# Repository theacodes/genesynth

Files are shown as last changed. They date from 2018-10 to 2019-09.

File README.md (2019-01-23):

# Genesynth

**Genesynth** is a music synthesizer module based around the Yamaha YM2612 FM Synthesis Chip, the same chip used in the Sega Genesis / Mega Drive.

## Why?

Because I wanted to. :)

## How?

This project is designed to use the Teensy 3.5 to control the YM2612 via USB MIDI.

More details for the hardware is available under the hardware folder, and more details on the firmware is under the firmware folder.

## License

This project is under the Apache License, Version 2.0. See LICENSE for more details.

If you use anything in this for a project, please let me know! I'd love to hear what you do with it. :)

# Building your own

This repository contains everything you'll need to build your own version of this synthesizer.

## Parts

You'll need to order all of the components in the three separate hardware modules under the `hardware` directory. You can use KiCAD to generate a BOM. These parts are readily available from Mouser and other distributors with the exception of the YM2612 chip - but this is easily obtainable on ebay.

Also note that you *must* use a Teensy 3.5. The Teensy 3.6 will *not* work as it's 3.3v logic and this design uses 5v logic.

You'll also need a 9v center-positive power supply.

## Ordering the PCBs

The gerbers for the PCBs are already created and are in the respective subdirectories under `hardware`. These are designed to fit within OSHPark's design rules, but I actually used PCBWay for my boards.

## Soldering components

You should *absolutely* use a socket for the YM2612 and the Teensy. Otherwise, this is all standard through-hole construction. Solder the smaller parts first followed by the larger parts.

## Connecting the boards.

There's three boards that make up the synth - the motherboard, a display board, and an audio board. The audio board connects to the *right* side of the motherboard, the display board to the *left*. You can connect these with wires or use pin headers and dupont connectors.

## Connect audio output.

The audo board has mono line out and stereo headphone out. You'll need to wire up the appropriate jack to the *right* side of the audio board.

## Assembling the case.

There's SVGs for creating a laser-cut case under `case`. You should be able to do this at any makerspace or using Ponoko. The case simply snaps together and the boards are mounted with standard M2 and M3 hardware.

## Preparing and programming the Teensy

Before powering on the synthesizer, **be sure to cut the USB power traces on the underside of the Teensy**. If you don't do this, **you will fry your board**. Once connected, you can build and upload the `firmware` using Teensyduino.

## Place patches on the SD card.

The synth needs patches on the SD card. Patches are in TFI format and many patch libraries are readily available. You should put patches into subdirectories of the SD card.

## All done!

You should now be able to boot the synthesizer, load patches, and play notes over MIDI. Have fun!

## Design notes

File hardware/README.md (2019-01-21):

# Genesynth Hardware

The hardware consists of three major components: the motherboard, the audio amplifier, and the display board.

## Motherboard

The motherboard contains:

* The Teensy 3.5. The 3.5 was chosen due to its 5V operating voltage for ease of compatibility with the YM2612. A 3.6 could be used if logic-level converters were added.
* A pair of LDO Voltage Regulators. These take 9V power and step it down to independent 5V supplies for digital and analog components. Since this powers the Teensy, the Teensy's USB voltage lines *must be cut*.
* The YM2612 itself. This chip should be socketed in case of a bad or damaged chip.

## Audio Amplifier

The audio amplifier is a relatively straightforward summing amplifier and buffer using the TL074 and is modeled after the Mega Amp mod for the Sega Genesis. This lets the Genesynth match the sound of the original hardware fairly closely. It's designed using through-hole components because that is what I'm most comfortable with at this time, but could easily be done using surface-mount. The audio board is powered by a dedicated analog 5V line provided by one of the motherboard's LDOs to completely eliminate noise.

## Display board

The display board holds a simple OLED display module and provides 4 tac switches for displaying and navigating the menu.

## Shared Libraries

I used the [SparkFun KiCad Libraries](https://github.com/sparkfun/SparkFun-KiCad-Libraries) for some of the footprints.

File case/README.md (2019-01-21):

# Case

This is the pattern for a laser-cut case to hold the Genesynth's various boards.

I made mine out of 1/8" acrylic and used standard M2 and M3 screws and spacers to put it all together.

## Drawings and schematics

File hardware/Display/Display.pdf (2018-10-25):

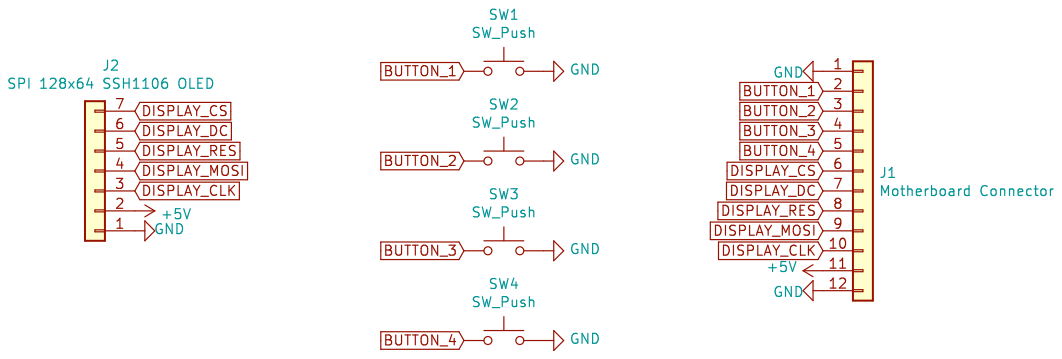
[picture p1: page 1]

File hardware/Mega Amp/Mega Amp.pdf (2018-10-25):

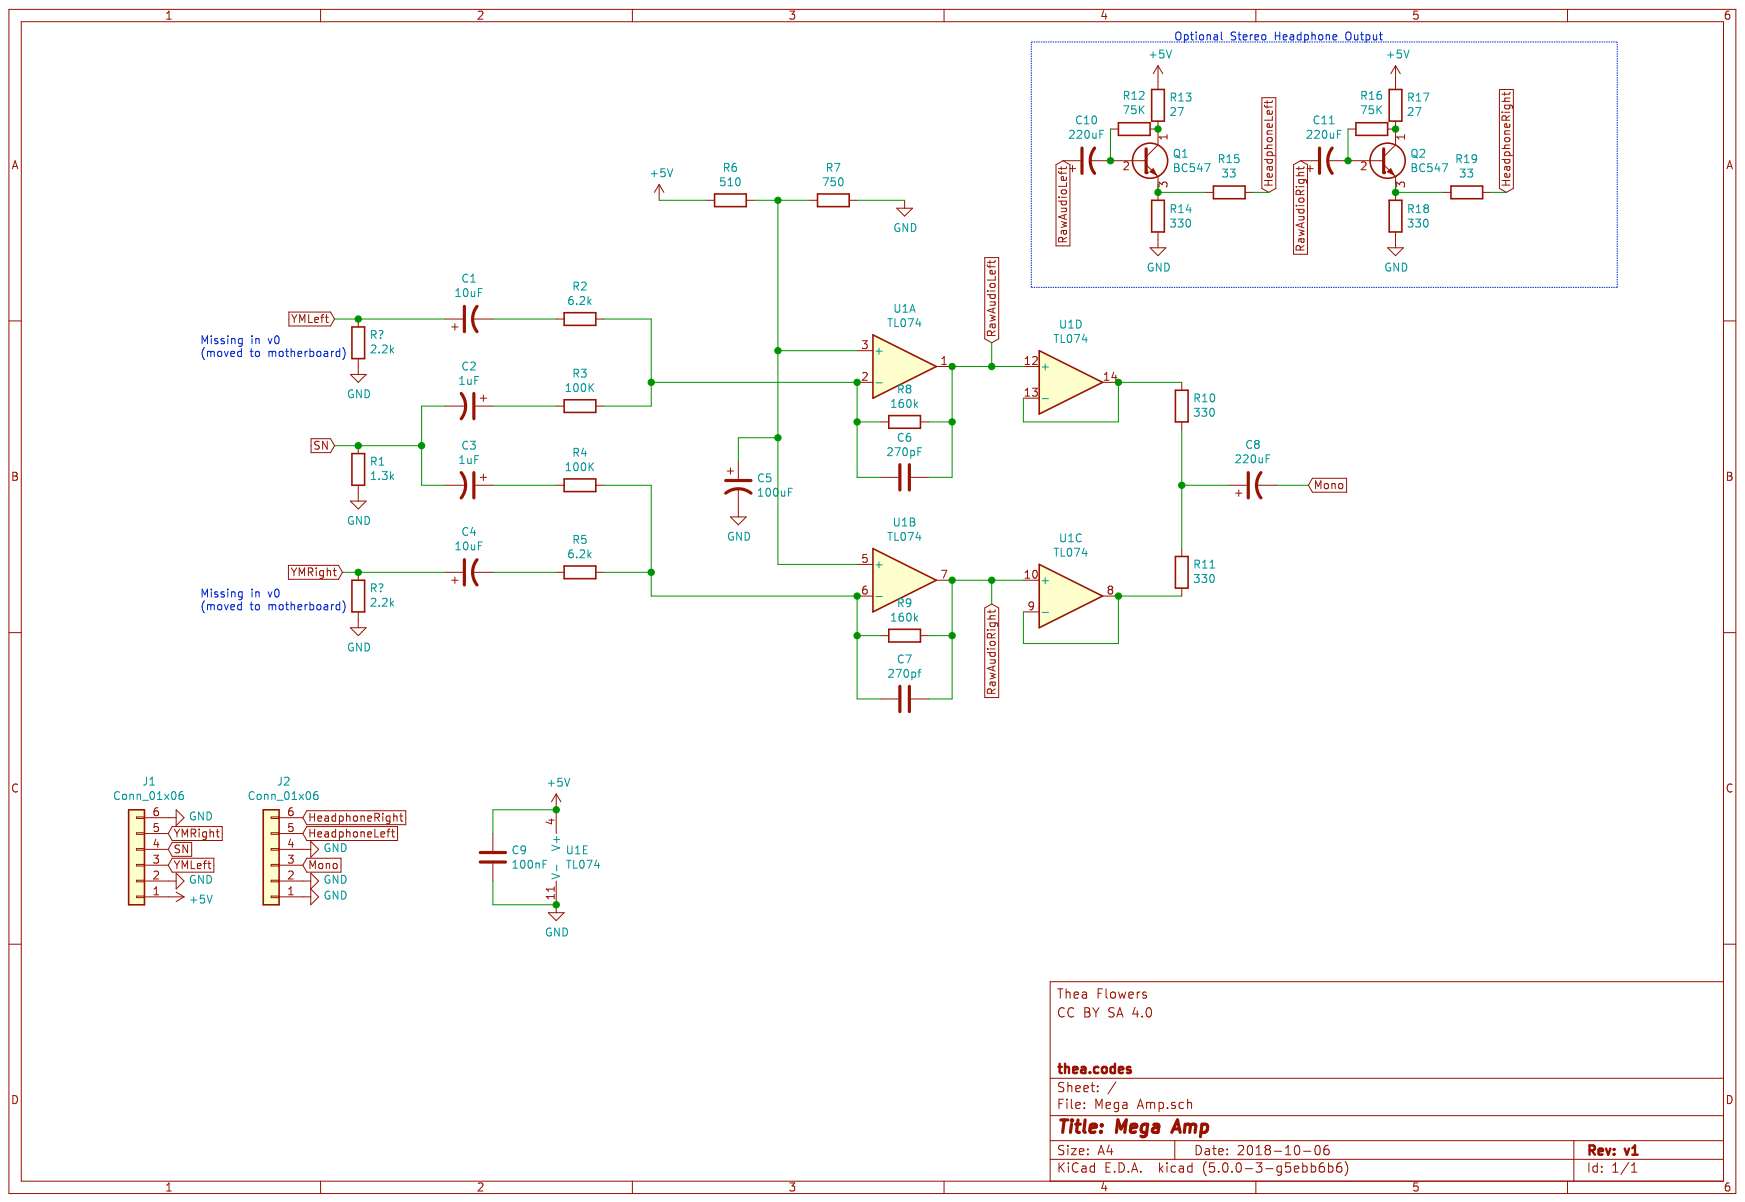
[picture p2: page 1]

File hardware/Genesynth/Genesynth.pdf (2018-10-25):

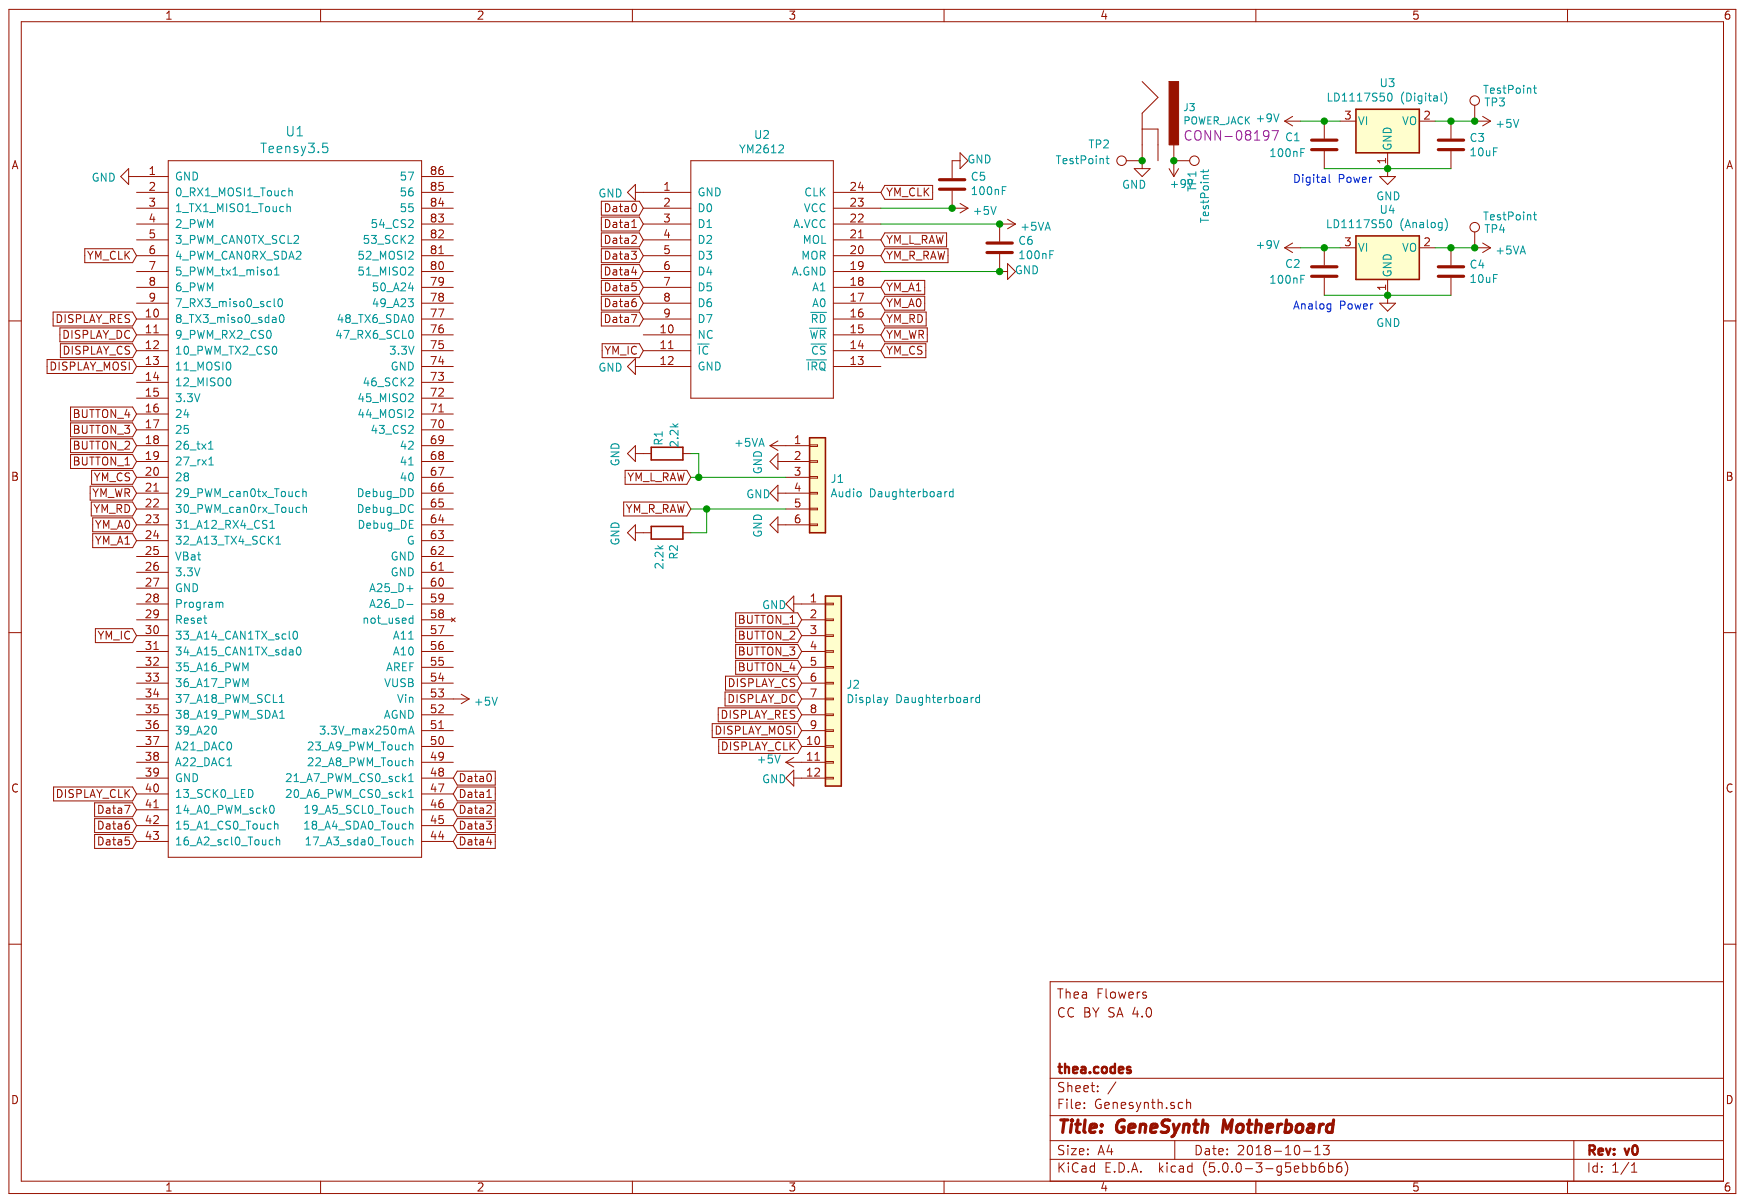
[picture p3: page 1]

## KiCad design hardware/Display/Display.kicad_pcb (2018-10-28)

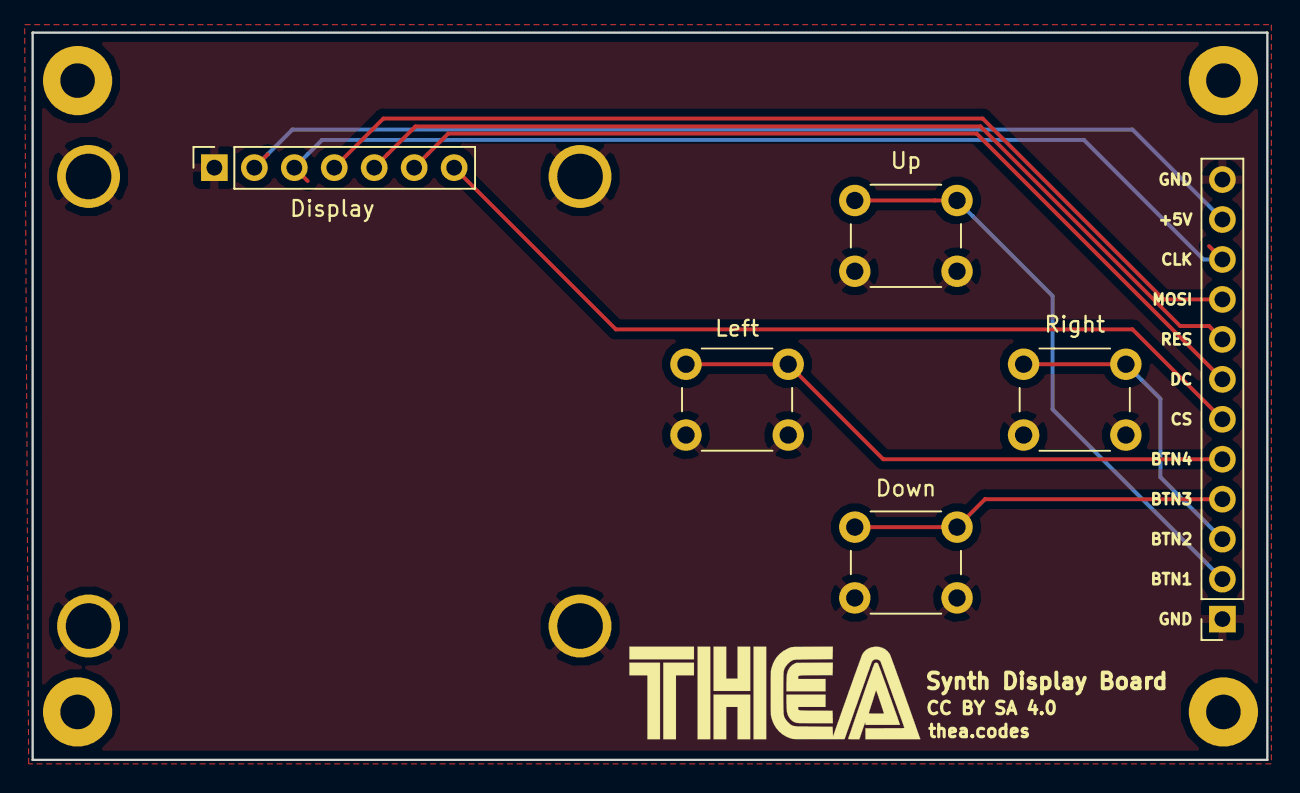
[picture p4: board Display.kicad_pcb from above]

Board: 2 copper layers, 78.5 x 46.2 mm, 6 parts (0 on the bottom side), 11 nets.

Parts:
Display: SPI 128x64 SSH1106 OLED; OLED
Down: SW_Push; SW_PUSH_6mm_H9.5mm
J1: Motherboard Connector; PinSocket_1x12_P2.54mm_Vertical
Left: SW_Push; SW_PUSH_6mm_H9.5mm
Right: SW_Push; SW_PUSH_6mm_H9.5mm
Up: SW_Push; SW_PUSH_6mm_H9.5mm

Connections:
+5V: Display.2, J1.11
BUTTON_1: J1.2, Up.1
BUTTON_2: J1.3, Right.1
BUTTON_3: Down.1, J1.4
BUTTON_4: J1.5, Left.1
DISPLAY_CLK: Display.3, J1.10
DISPLAY_CS: Display.7, J1.6
DISPLAY_DC: Display.6, J1.7
DISPLAY_MOSI: Display.4, J1.9
DISPLAY_RES: Display.5, J1.8
GND: Display.1, Down.2, J1.1, J1.12, Left.2, Right.2, Up.2

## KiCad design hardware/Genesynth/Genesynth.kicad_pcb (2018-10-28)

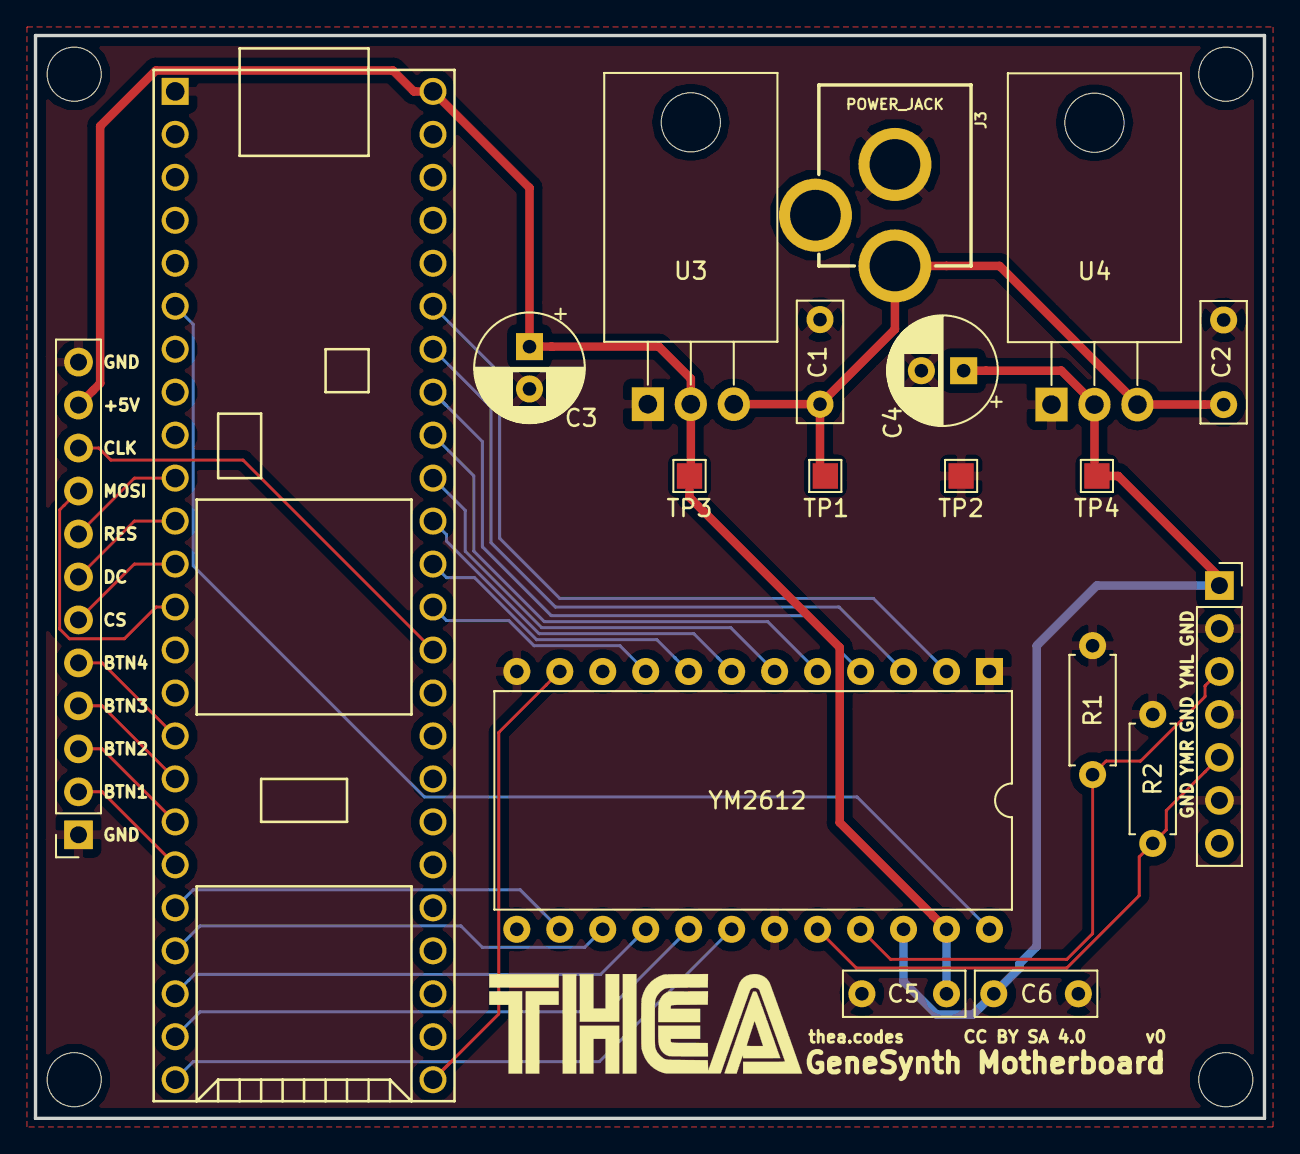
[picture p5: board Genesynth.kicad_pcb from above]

Board: 2 copper layers, 72.6 x 64.0 mm, 19 parts (0 on the bottom side), 30 nets.

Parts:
C1, C2, C5, C6: 100nF; C_Disc_D7.0mm_W2.5mm_P5.00mm
C3, C4: 10uF; CP_Radial_D6.3mm_P2.50mm
J1: Audio Daughterboard; PinSocket_1x07_P2.54mm_Vertical
J2: Display Daughterboard; PinSocket_1x12_P2.54mm_Vertical
J3: POWER_JACK; POWER_JACK_PTH
R1, R2: 2.2k; R_Axial_DIN0207_L6.3mm_D2.5mm_P7.62mm_Horizontal
TP1, TP2, TP3, TP4: TestPoint; TestPoint_Pad_1.5x1.5mm
U1: Teensy3.5; TeensyReduced
U2: YM2612; DIP-24_W15.24mm
U3: LD1117S50 (Digital); TO-220-3_Horizontal_TabDown
U4: LD1117S50 (Analog); TO-220-3_Horizontal_TabDown

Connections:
+5V: C3.1, C5.1, J2.11, TP3.1, U1.53, U2.23, U3.2
+5VA: C4.1, C6.1, J1.1, TP4.1, U2.22, U4.2
+9V: C1.1, C2.1, J3.PWR, TP1.1, U3.3, U4.3
BUTTON_1: J2.2, U1.19
BUTTON_2: J2.3, U1.18
BUTTON_3: J2.4, U1.17
BUTTON_4: J2.5, U1.16
DISPLAY_CLK: J2.10, U1.40
DISPLAY_CS: J2.6, U1.12
DISPLAY_DC: J2.7, U1.11
DISPLAY_MOSI: J2.9, U1.13
DISPLAY_RES: J2.8, U1.10
Data0: U1.48, U2.2
Data1: U1.47, U2.3
Data2: U1.46, U2.4
Data3: U1.45, U2.5
Data4: U1.44, U2.6
Data5: U1.43, U2.7
Data6: U1.42, U2.8
Data7: U1.41, U2.9
GND: C1.2, C2.2, C3.2, C4.2, C5.2, C6.2, J1.2, J1.4, J1.6, J2.1, J2.12, J3.GND, R1.2, R2.2, TP2.1, U1.1, U2.1, U2.12, U2.19, U3.1, U4.1
YM_A0: U1.23, U2.17
YM_A1: U1.24, U2.18
YM_CLK: U1.6, U2.24
YM_CS: U1.20, U2.14
YM_IC: U1.30, U2.11
YM_L_RAW: J1.3, R1.1, U2.21
YM_RD: U1.22, U2.16
YM_R_RAW: J1.5, R2.1, U2.20
YM_WR: U1.21, U2.15

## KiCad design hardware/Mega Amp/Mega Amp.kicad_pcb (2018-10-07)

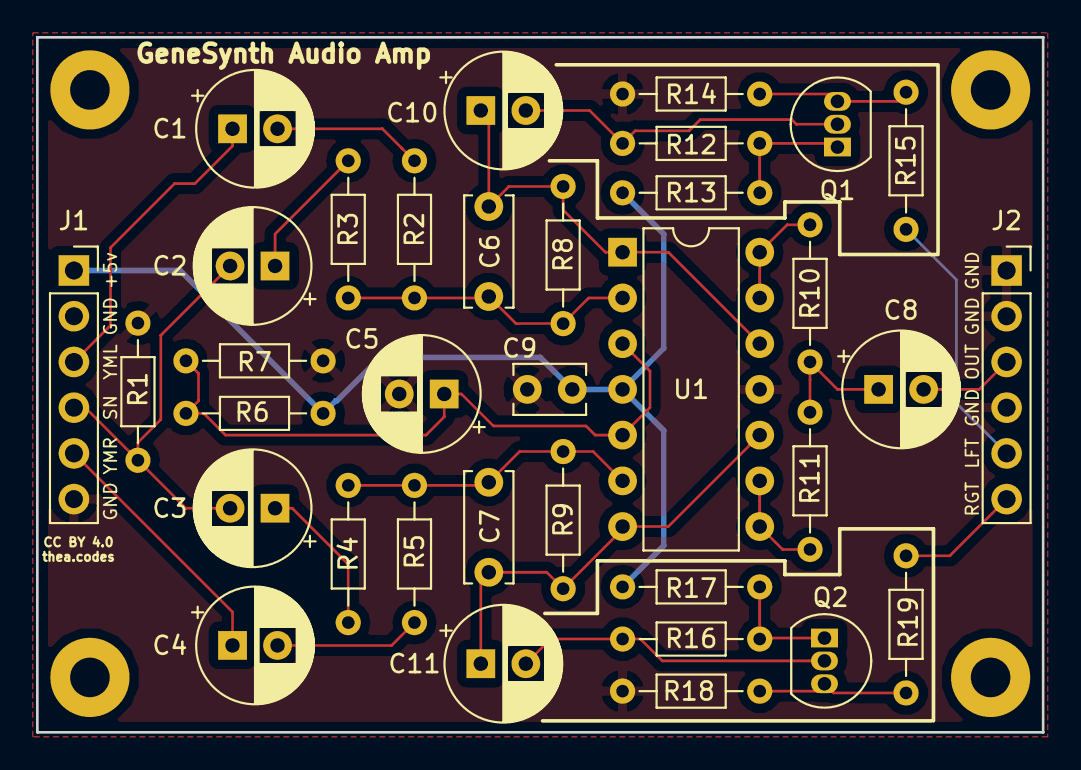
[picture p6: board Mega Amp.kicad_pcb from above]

Board: 2 copper layers, 55.9 x 38.6 mm, 35 parts (0 on the bottom side), 26 nets.

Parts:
C1, C4: 10uF; CP_Radial_D6.3mm_P2.50mm
C2, C3: 1uF; CP_Radial_D6.3mm_P2.50mm
C5: 100uF; CP_Radial_D6.3mm_P2.50mm
C6: 270pF; C_Disc_D6.0mm_W2.5mm_P5.00mm
C7: 270pf; C_Disc_D6.0mm_W2.5mm_P5.00mm
C8, C10, C11: 220uF; CP_Radial_D6.3mm_P2.50mm
C9: 100nF; C_Disc_D3.8mm_W2.6mm_P2.50mm
J1, J2: Conn_01x06; PinSocket_1x06_P2.54mm_Vertical
Q1, Q2: BC547; TO-92_Inline
R1: R; R_Axial_DIN0204_L3.6mm_D1.6mm_P7.62mm_Horizontal
R2, R5: 51K; R_Axial_DIN0204_L3.6mm_D1.6mm_P7.62mm_Horizontal
R3, R4: 100K; R_Axial_DIN0204_L3.6mm_D1.6mm_P7.62mm_Horizontal
R6: 510; R_Axial_DIN0204_L3.6mm_D1.6mm_P7.62mm_Horizontal
R7: 750; R_Axial_DIN0204_L3.6mm_D1.6mm_P7.62mm_Horizontal
R8, R9: 160; R_Axial_DIN0204_L3.6mm_D1.6mm_P7.62mm_Horizontal
R10, R11, R14, R18: 330; R_Axial_DIN0204_L3.6mm_D1.6mm_P7.62mm_Horizontal
R12, R16: 75K; R_Axial_DIN0204_L3.6mm_D1.6mm_P7.62mm_Horizontal
R13, R17: 27; R_Axial_DIN0204_L3.6mm_D1.6mm_P7.62mm_Horizontal
R15, R19: 33; R_Axial_DIN0204_L3.6mm_D1.6mm_P7.62mm_Horizontal
U1: TL074; DIP-14_W7.62mm

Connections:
+5V: C9.1, J1.1, R6.2, R13.2, R17.2, U1.4
GND: C5.2, C9.2, J1.2, J1.6, J2.1, J2.2, J2.4, R1.1, R7.1, R14.2, R18.2, U1.11
HeadphoneLeft: J2.5, R15.2
HeadphoneRight: J2.6, R19.2
Mono: C8.2, J2.3
unnamed: C1.2, R2.2
unnamed: C2.1, R3.2
unnamed: C3.1, R4.2
unnamed: C4.2, R5.2
unnamed: C5.1, R6.1, R7.2, U1.3, U1.5
unnamed: C6.2, R2.1, R3.1, R8.2, U1.2
unnamed: C7.2, R4.1, R5.1, R9.2, U1.6
unnamed: C8.1, R10.1, R11.2
unnamed: C10.2, Q1.2, R12.1
unnamed: C11.2, Q2.2, R16.1
unnamed: Q1.1, R12.2, R13.1
unnamed: Q1.3, R14.1, R15.1
unnamed: Q2.1, R16.2, R17.1
unnamed: Q2.3, R18.1, R19.1
unnamed: R10.2, U1.13, U1.14
unnamed: R11.1, U1.8, U1.9
RawAudioLeft: C6.1, C10.1, R8.1, U1.1, U1.12
RawAudioRight: C7.1, C11.1, R9.1, U1.7, U1.10
SN: C2.2, C3.2, J1.4, R1.2
YMLeft: C1.1, J1.3
YMRight: C4.1, J1.5

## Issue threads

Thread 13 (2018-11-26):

figure out what to do with the modwheel

theacodes, 2018-11-26:

theacodes, 2019-01-15:
I should implement a modulation "matrix" - with the modulation source being fixed to just the mod wheel but with many modulation destinations.

Closed 2019-09-05.

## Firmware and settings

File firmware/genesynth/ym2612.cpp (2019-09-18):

#include <Arduino.h>

#include "hardware_constants.h"
#include "nanodelay.h"
#include "ym2612.h"

namespace thea {
namespace ym2612 {

/* Global state */

struct WriteCommand {
  uint8_t address = 0;
  uint8_t data = 0;
  uint8_t port = 0;
};

// 200 is a good size here, as it takes about 150 commands to write a full
// patch.
WriteCommand write_buffer[200];
const size_t write_buffer_size = sizeof(write_buffer) / sizeof(WriteCommand);
size_t write_buffer_len = 0;
size_t write_buffer_start = 0;
size_t write_buffer_end = 0;

LatencyInfo latency;

/* Low-level functions */

static void initialize_clock() {
  /* Uses PWM to generate clock for the YM2612 */
  pinMode(YM_CLOCK, OUTPUT);
  analogWriteFrequency(YM_CLOCK, YM_CLOCK_FREQ);
  analogWrite(YM_CLOCK, 128);
  delay(50); // wait a moment for the clock.
}

static void reset() {
  /* Reset the YM's state. */
  digitalWriteFast(YM_IC, HIGH);
  delayMicroseconds(YM_RESET_WAIT);
  digitalWriteFast(YM_IC, LOW);
  delayMicroseconds(YM_RESET_WAIT);
  digitalWriteFast(YM_IC, HIGH);
  delayMicroseconds(YM_RESET_WAIT);
}

inline static void input_enable() {
  for (int i = 0; i < 8; i++) {
    pinMode(YM_DATA - i, INPUT);
  }
}

inline static void output_enable() {
  for (int i = 0; i < 8; i++) {
    pinMode(YM_DATA - i, OUTPUT);
  }
}

inline static uint8_t read_data_lines() {
  uint8_t out = 0;
  for (int i = 0; i < 8; i++) {
    out |= digitalReadFast(YM_DATA - i) << i;
  }
  return out;
}

inline static void set_data_lines(byte b) {
  /* Sets the data lines to the YM to the given byte. */
  for (int i = 0; i < 8; i++) {
    digitalWriteFast(YM_DATA - i, ((b >> i) & 1));
  }
}

inline static void wait_ready() {
  // Always wait a few nano seconds before toggling pin directions.
  delay10ns(YM_WRITE_WAIT);

  // Switch data bus to input YM -> uC.
  input_enable();

  // Switch A0 to inactive to read the data byte, pull CS and RD low again.
  digitalWriteFast(YM_WR, HIGH);
  digitalWriteFast(YM_A1, LOW);
  digitalWriteFast(YM_A0, LOW);
  digitalWriteFast(YM_RD, LOW);
  delay10ns(YM_WRITE_WAIT);
  digitalWriteFast(YM_CS, LOW);
  delay10ns(YM_WRITE_WAIT);

  // Wait until the bus' 7th bit is 0.
  int count = 0;
  uint8_t state = 0;
  while (count < YM_MAX_WAIT_CYCLES) {
    __asm__ volatile("nop");
    count++;
    // Wait at *least* 20 cycles for the pins to read accurately.
    if (count < 20)
      continue;
    state = read_data_lines();
    if ((state & (1 << 7)) == 0)
      break;
  }

  // Disable the chip and read pins.
  digitalWriteFast(YM_RD, HIGH);
  digitalWriteFast(YM_CS, HIGH);
  delay10ns(YM_WRITE_WAIT);

  // Switch data bus back to ouput. uC -> YM.
  output_enable();

  // Debug
  if (count == YM_MAX_WAIT_CYCLES) {
    Serial.printf("Warning, waited too many cycles for ready, last state: %x, %x, %i.\n", state, (1 << 7),
                  state & (1 << 7));
    latency.hit_max_wait_cycles = true;
  }
}

static void write_out_reg(uint8_t address, uint8_t data, uint8_t port) {
  // Serial.printf("Writing %02x to %02x on %i\n", data, address, port);
  auto start = micros();

  // Wait for any previous writes to finish before writing.
  wait_ready();

  // Write the register address first.
  digitalWriteFast(YM_A1, port);
  digitalWriteFast(YM_A0, LOW);
  set_data_lines(address);

  // technically we should give *some* time between setting the bytes and
  // pulling the pins, but it seems to work fine without that.
  digitalWriteFast(YM_CS, LOW);
  digitalWriteFast(YM_WR, LOW);

  // We must wait for the chip to finish reading our address before loading in the
  // next byte.
  // We shouldn't raise the WR and CS until at least YM_WRITE_WAIT have passed.
  delay10ns(YM_WRITE_WAIT);
  digitalWriteFast(YM_WR, HIGH);
  digitalWriteFast(YM_CS, HIGH);

  // Same as above, but with A0 high to write the register data.
  digitalWriteFast(YM_A0, HIGH);
  set_data_lines(data);
  delay10ns(YM_WRITE_WAIT);
  digitalWriteFast(YM_CS, LOW);
  digitalWriteFast(YM_WR, LOW);
  delay10ns(YM_WRITE_WAIT);

  // Disable the chip and write pins.
  digitalWriteFast(YM_WR, HIGH);
  digitalWriteFast(YM_CS, HIGH);
  delay10ns(YM_WRITE_WAIT);

  // Update latency calculations
  latency.last = micros() - start;
  if (latency.max < latency.last)
    latency.max = latency.last;
  latency.average = (latency.average_alpha * latency.last) + (1.f - latency.average_alpha) * latency.average;
  latency.bytes_written++;
}

/* Top-level functions */

void setup() {
  /* Setup the YM's pins. */
  for (int i = 0; i < 8; i++) {
    pinMode(YM_DATA - i, OUTPUT);
    digitalWriteFast(YM_DATA - i, LOW);
  }
  pinMode(YM_IC, OUTPUT);
  pinMode(YM_A1, OUTPUT);
  pinMode(YM_A0, OUTPUT);
  pinMode(YM_WR, OUTPUT);
  pinMode(YM_CS, OUTPUT);
  pinMode(YM_RD, OUTPUT);
  digitalWriteFast(YM_IC, HIGH);
  digitalWriteFast(YM_A1, LOW);
  digitalWriteFast(YM_A0, LOW);
  digitalWriteFast(YM_WR, HIGH);
  digitalWriteFast(YM_CS, HIGH);
  digitalWriteFast(YM_RD, HIGH);

  initialize_clock();
  reset();
}

void loop() {
  if (!write_buffer_len)
    return;
  // Serial.printf("There are %u commands to send.\n", write_buffer_len);
  while (write_buffer_len) {
    // Serial.printf("start: %u, end: %u, len: %u\n", write_buffer_start, write_buffer_end, write_buffer_len);
    auto command = write_buffer[write_buffer_start];
    write_out_reg(command.address, command.data, command.port);
    write_buffer_start = (write_buffer_start + 1) % write_buffer_size;
    write_buffer_len--;
  }
}

const LatencyInfo &get_latency() { return latency; }

void set_reg(uint8_t address, uint8_t data, uint8_t port) {
  /* Queues a write command into the command buffer.*/

  // Is this one of the parameter modifications? If so, de-duplicate the
  // command to prevent overwhelming the ym2612.
  if (address >= 0x30 && address <= 0x90) {
    // step through the whole buffer and see if there's already a command
    // queued. If so, modify it instead of inserting this.
    for (auto i = 0; i < write_buffer_len; i++) {
      auto &command = write_buffer[(write_buffer_start + i) % write_buffer_size];
      if (command.address == address && command.port == port) {
        // Serial.printf("Deduplicated a write to %02x:%u old: %02x new: %02x\n", address, port, command.data, data);
        command.data = data;
        return;
      }
    }
  }

  // Otherwise, insert the new command.
  write_buffer[write_buffer_end].address = address;
  write_buffer[write_buffer_end].data = data;
  write_buffer[write_buffer_end].port = port;
  write_buffer_end = (write_buffer_end + 1) % write_buffer_size;
  write_buffer_len++;
}

void set_reg(uint8_t address, uint8_t data) { return set_reg(address, data, 0); }

void set_channel_freq(int channel, float freq) {
  // From YM2612 Datasheet:
  // Freq Number = (144 * note * 2^20 / Clock) / 2^(block-1)
  // (change to 2^20, because it seemed to be setting the wrong octaive).
  // Figure out the base frequency number first, then start iterating through
  // blocks until it's within range 0 < freq_int < 2000
  float base_freq = 144.f * freq * pow(2.f, 19) / 7500000.f;
  uint32_t freq_int = 2001;

  int block = 1;
  while (freq_int > 2000) {
    freq_int = base_freq / pow(2.f, block - 1);
    block++;
  }

  int port = channel < 3 ? 0 : 1;
  uint8_t channel_offset = (channel % 3);
  set_reg(0xA4 + channel_offset, (block << 3) | (freq_int >> 8), port);
  set_reg(0xA0 + channel_offset, freq_int & 0xFF, port);
}

void play_note(int channel) {
  int port = channel < 3 ? 0 : 1;
  uint8_t channel_offset = (channel % 3);
  uint8_t key_offset = channel_offset | (port << 2);
  set_reg(0x28, 0xF0 | key_offset);
}

void stop_note(int channel) {
  int port = channel < 3 ? 0 : 1;
  uint8_t channel_offset = (channel % 3);
  uint8_t key_offset = channel_offset | (port << 2);
  set_reg(0x28, key_offset);
}

void set_lfo(bool enable, uint8_t freq) {
  if (freq > 7)
    freq = 7; // 3 bits (0-7)
  uint8_t lfo_reg = (enable << 3) | (freq);
  set_reg(0x22, lfo_reg);
}

/* Channel/OperatorPatch implementations */

static void write_operator_values(int port, int channel, int operator_num, OperatorPatch &oper,
                                  ChannelPatch::WriteOption option) {
  // wrap the write option around if its an operator specific option in *this* operator's range.
  if (option >= 10 * operator_num && option <= 10 * (operator_num + 1)) {
    option = ChannelPatch::WriteOption(option % 10);
  }
  // If this wasn't an operator-specific option and also not a option to write
  // All params, then there's nothing to do here.
  else if (option != ChannelPatch::WriteOption::ALL) {
    return;
  }

  uint8_t operator_offset = 4 * operator_num;

  uint8_t dt1_mul_byte = (oper.DT1 << 4) | (oper.MUL & 0xF);
  uint8_t tl_byte = oper.TL & 0x7F;
  uint8_t rs_ar_byte = (oper.RS << 6) | (oper.AR & 0x1F);
  uint8_t am_d1r_byte = (oper.AM << 7) | (oper.D1R & 0x1F);
  uint8_t d2r_byte = oper.D2R & 0x1F;
  uint8_t d1l_rr_byte = (oper.D1L << 4) | (oper.RR & 0xF);

  if (option == ChannelPatch::WriteOption::ALL or option == ChannelPatch::WriteOption::OP0_DT1 or
      option == ChannelPatch::WriteOption::OP0_MUL) {
    set_reg(0x30 + operator_offset + channel, dt1_mul_byte, port);
  }

  if (option == ChannelPatch::WriteOption::ALL or option == ChannelPatch::WriteOption::OP0_TL) {
    set_reg(0x40 + operator_offset + channel, tl_byte, port);
  }

  if (option == ChannelPatch::WriteOption::ALL or option == ChannelPatch::WriteOption::OP0_RS or
      option == ChannelPatch::WriteOption::OP0_AR) {
    set_reg(0x50 + operator_offset + channel, rs_ar_byte, port);
  }

  if (option == ChannelPatch::WriteOption::ALL or option == ChannelPatch::WriteOption::OP0_AM or
      option == ChannelPatch::WriteOption::OP0_D1R) {
    set_reg(0x60 + operator_offset + channel, am_d1r_byte, port);
  }

  if (option == ChannelPatch::WriteOption::ALL or option == ChannelPatch::WriteOption::OP0_D2R) {
    set_reg(0x70 + operator_offset + channel, d2r_byte, port);
  }

  if (option == ChannelPatch::WriteOption::ALL or option == ChannelPatch::WriteOption::OP0_D1L or
      option == ChannelPatch::WriteOption::OP0_RR) {
    set_reg(0x80 + operator_offset + channel, d1l_rr_byte, port);
  }
};

void ChannelPatch::write_to_channel(uint8_t channel, ChannelPatch::WriteOption option) {
  int port = channel < 3 ? 0 : 1;
  channel = channel % 3;

  for (int i = 0; i < 4; i++) {
    write_operator_values(port, channel, i, operators[i], option);
  }

  // Setup channel
  uint8_t feedback_algorithm_byte = (feedback << 3) | (algorithm & 0x7);

  if (option == WriteOption::ALL or option == WriteOption::FEEDBACK or option == WriteOption::ALGORITHM) {
    set_reg(0xB0 + channel, feedback_algorithm_byte, port);
  }

  if (option == WriteOption::ALL || option == WriteOption::LFO_AMS || option == WriteOption::LFO_FMS) {
    // Enable output on both speakers (for now) with 0xC0
    uint8_t lr_ams_fms_byte = 0xC0 | (lfo_ams << 5) | (lfo_fms);
    set_reg(0xB4 + channel, lr_ams_fms_byte, port);
  }
};

void ChannelPatch::set_parameter(ChannelPatch::WriteOption option, uint8_t value, bool normalized) {
  if (normalized)
    value = normalized_to_ym2612(value, option);

  /* Global parameters */
  switch (option) {
  case WriteOption::ALGORITHM:
    algorithm = value;
    return;
  case WriteOption::FEEDBACK:
    feedback = value;
    return;
  case WriteOption::LFO_FMS:
    lfo_fms = value;
    return;
  case WriteOption::LFO_AMS:
    lfo_ams = value;
    return;
  default:
    break;
  }

  /* Operator parameters */
  if (option > thea::ym2612::ChannelPatch::WriteOption::OP3_AM) {
    /* Unknown option */
    return;
  }

  auto normalized_option = thea::ym2612::ChannelPatch::WriteOption(option % 10);
  auto operator_no = option / 10;

  switch (normalized_option) {
  case WriteOption::OP0_DT1:
    operators[operator_no].DT1 = value;
    break;
  case WriteOption::OP0_MUL:
    operators[operator_no].MUL = value;
    break;
  case WriteOption::OP0_TL:
    operators[operator_no].TL = value;
    break;
  case WriteOption::OP0_AR:
    operators[operator_no].AR = value;
    break;
  case WriteOption::OP0_D1R:
    operators[operator_no].D1R = value;
    break;
  case WriteOption::OP0_D2R:
    operators[operator_no].D2R = value;
    break;
  case WriteOption::OP0_D1L:
    operators[operator_no].D1L = value;
    break;
  case WriteOption::OP0_RR:
    operators[operator_no].RR = value;
    break;
  case WriteOption::OP0_RS:
    operators[operator_no].RS = value;
    break;
  case WriteOption::OP0_AM:
    operators[operator_no].AM = value;
    break;
  default:
    break;
  }
}

/* Normalization / denormalization routines */

uint8_t ym2612_to_normalized(uint8_t value, ChannelPatch::WriteOption option) {
  // TODO
  return 0;
}

uint8_t normalized_to_ym2612(uint8_t value, ChannelPatch::WriteOption option) {
  // Is this a global parameter?
  switch (option) {
  case ChannelPatch::WriteOption::ALGORITHM:
    return map(value, 0, 127, 0, 7);
  case ChannelPatch::WriteOption::FEEDBACK:
    return map(value, 0, 127, 0, 7);
  case ChannelPatch::WriteOption::LFO_FMS:
    return map(value, 0, 127, 0, 7);
  case ChannelPatch::WriteOption::LFO_AMS:
    return map(value, 0, 127, 0, 3);
  default:
    break;
  }

  // This is an operator value.
  auto normalized_option = thea::ym2612::ChannelPatch::WriteOption(option % 10);
  uint8_t operator_no = option / 10;

  // All operator parameters are actually inverted - the lower values are
  // associated with what humans would think are "higher" knob values. That is
  // to say, if the parameter were "volume", 0 would be the loudest and 127
  // would be the softest. No frickin' clue why Yamaha did this.
  value = 127 - value;

  switch (normalized_option) {
  case thea::ym2612::ChannelPatch::WriteOption::OP0_DT1:
    return map(value, 0, 127, 0, 7);
  case thea::ym2612::ChannelPatch::WriteOption::OP0_MUL:
    return map(value, 0, 127, 0, 15);
  case thea::ym2612::ChannelPatch::WriteOption::OP0_TL:
    return value;
  case thea::ym2612::ChannelPatch::WriteOption::OP0_AR:
    return map(value, 0, 127, 0, 31);
  case thea::ym2612::ChannelPatch::WriteOption::OP0_D1R:
    return map(value, 0, 127, 0, 31);
  case thea::ym2612::ChannelPatch::WriteOption::OP0_D2R:
    return map(value, 0, 127, 0, 31);
  case thea::ym2612::ChannelPatch::WriteOption::OP0_D1L:
    return map(value, 0, 127, 0, 15);
  case thea::ym2612::ChannelPatch::WriteOption::OP0_RR:
    return map(value, 0, 127, 0, 15);
  case thea::ym2612::ChannelPatch::WriteOption::OP0_RS:
    return map(value, 0, 127, 0, 3);
  case thea::ym2612::ChannelPatch::WriteOption::OP0_AM:
    return value;
  default:
    return 0;
  }

  return 0;
}

}; // namespace ym2612
}; // namespace thea

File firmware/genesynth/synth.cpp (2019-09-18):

#include <Arduino.h>
#include <EEPROM.h>

#include "hardware_constants.h"
#include "src/theacommon/note_stack.h"
#include "synth.h"
#include "tfi_parser.h"

namespace thea {
namespace synth {

#define YM_CHANNELS 6

/*
  Patch management and eeprom interaction.
*/

thea::ym2612::ChannelPatch patch;
thea::ym2612::ChannelPatch::WriteOption last_write_option;
unsigned long last_patch_modify_time;
bool is_lfo_enabled;
uint8_t lfo_freq;

void write_patch_to_eeprom(thea::ym2612::ChannelPatch &patch) {
  auto byte_array = (char *)&patch;
  for (size_t i = 0; i < sizeof(patch); i++) {
#if DEBUG_EEPROM_RW
    Serial.printf("%02X ", byte_array[i]);
    if (i % 16 == 15)
      Serial.printf("\n");
#endif

    EEPROM.update(EEPROM_PATCH_ADDR + i, byte_array[i]);
  }

#if DEBUG_EEPROM_RW
  Serial.printf("\n\n");
#endif

  Serial.printf("Wrote patch to EEPROM, wrote %i bytes.\n", sizeof(patch));
}

void read_patch_from_eeprom(thea::ym2612::ChannelPatch *patch) {
  auto byte_array = (char *)patch;
  for (size_t i = 0; i < sizeof(*patch); i++) {
    char value = EEPROM.read(EEPROM_PATCH_ADDR + i);

#if DEBUG_EEPROM_RW
    Serial.printf("%02X ", value);
    if (i % 16 == 15)
      Serial.printf("\n");
#endif

    byte_array[i] = value;
  }

#if DEBUG_EEPROM_RW
  Serial.printf("\n\n");
#endif

  Serial.printf("Read patch from EEPROM, read %i bytes.\n", sizeof(*patch));
  Serial.printf("Patch name: %s\n", patch->name);
}

void modify_patch_parameter(thea::ym2612::ChannelPatch::WriteOption option, uint8_t normalized_value) {
  patch.set_parameter(option, normalized_value, true);
}

void update_patch(thea::ym2612::ChannelPatch::WriteOption option) {
  for (uint8_t i = 0; i < YM_CHANNELS; i++) {
    thea::synth::patch.write_to_channel(i, option);
  }
  last_write_option = option;
  last_patch_modify_time = micros();
}

void load_patch(SdFile &file, SdFile *folder) {
  bool success = thea::tfi::load(file, folder, &patch);

  if (!success) {
    Serial.printf("Failed to load patch!");
  }

  update_patch();
  write_patch_to_eeprom(patch);
}

void load_last_patch() {
  read_patch_from_eeprom(&patch);
  update_patch();
}

void save_patch(SdFile &file) { thea::tfi::save(file, patch); };

void enable_lfo() {
  is_lfo_enabled = true;
  thea::ym2612::set_lfo(is_lfo_enabled, lfo_freq);
  last_write_option = thea::ym2612::ChannelPatch::WriteOption::LFO_AMS;
  last_patch_modify_time = micros();
}

void disable_lfo() {
  is_lfo_enabled = false;
  thea::ym2612::set_lfo(is_lfo_enabled, lfo_freq);
  // Should be LFO_ENABLE, but I haven't rolled that into the patch logic (it's global for now).
  last_write_option = thea::ym2612::ChannelPatch::WriteOption::LFO_AMS;
  last_patch_modify_time = micros();
}

bool lfo_enabled() { return is_lfo_enabled; }

void set_lfo_freq(uint8_t value) {
  lfo_freq = map(value, 0, 127, 0, 7);
  thea::ym2612::set_lfo(is_lfo_enabled, lfo_freq);
  // Should be LFO_ENABLE, but I haven't rolled that into the patch logic (it's global for now).
  last_write_option = thea::ym2612::ChannelPatch::WriteOption::LFO_AMS;
  last_patch_modify_time = micros();
}

uint8_t get_lfo_freq() { return lfo_freq; }

void set_lfo_fms(uint8_t value) {
  patch.set_parameter(thea::ym2612::ChannelPatch::WriteOption::LFO_FMS, value, true);
  update_patch(thea::ym2612::ChannelPatch::WriteOption::LFO_FMS);
}

void set_lfo_ams(uint8_t value) {
  patch.set_parameter(thea::ym2612::ChannelPatch::WriteOption::LFO_AMS, value, true);
  update_patch(thea::ym2612::ChannelPatch::WriteOption::LFO_FMS);
}

/*
  Note handling
*/

inline bool approximately_equal(float a, float b, float epsilon) {
  return fabs(a - b) <= ((fabs(a) < fabs(b) ? fabs(b) : fabs(a)) * epsilon);
}

/* Encapsulates common functionality for poly, mono, and unison. */
class NoteStrategy {
public:
  virtual ~NoteStrategy(){};

  virtual void reset() = 0;

  /* Called every loop() to update pitches, etc. */
  virtual void update() = 0;

  virtual void note_on(uint8_t note, float pitch) = 0;
  virtual void note_off(uint8_t note) = 0;

  virtual void pitch_bend(float offset) {
    // Adjustable: a 1.0 multiplier means that the pitch wheel all the way up *doubles* the frequency.
    // A 0.5 multipler lowers the range a bit, making it a bit more musically usabe.
    offset *= 0.5f;

    pitch_bend_multiplier = 1.f + offset;
  }

protected:
  // Pitch bend is applied to all modes when setting the channel frequency.
  float pitch_bend_multiplier = 1.f;
};

/* Unison strategy is used for both monophonic and unison modes. Mono just
 uses one voice. */
class UnisonStrategy : public NoteStrategy {
public:
  virtual void reset() {
    note_stack.clear();
    for (uint8_t i = 0; i < YM_CHANNELS; i++) {
      thea::ym2612::stop_note(i);
    }
  }

  virtual void update() {
    // This is only needed if there's notes on the stack and if glide is enabled.
    if (note_stack.is_empty() || !glide)
      return;

    auto current_note = note_stack.top();

    // Glide is normalized (0-1.f), mulitply it by a useful time constant.
    float glide_denominator = glide_amount * 300.0f;
    // Avoid divide by 0.
    if (glide_denominator < 1.0f)
      glide_denominator = 1.0f;

    for (uint8_t i = 0; i < voices; i++) {
      auto target_pitch = current_note.pitch * channel_spread_multipliers[i];

      if (active_pitches[i] == target_pitch)
        continue;

      active_pitches[i] += ((target_pitch - active_pitches[i]) / glide_denominator) * channel_spread_multipliers[i];

      if (approximately_equal(active_pitches[i], target_pitch, 0.01f)) {
        active_pitches[i] = target_pitch;
      }

      thea::ym2612::set_channel_freq(i, active_pitches[i] * pitch_bend_multiplier);
    }
  }

  virtual void note_on(uint8_t note, float pitch) {
    bool retrigger = !glide || note_stack.is_empty();

    // If glide is off, we'll need to stop
    // the previous note.
    bool stop_previous = !glide;

    note_stack.push(note, pitch);

    if (retrigger) {
      for (uint8_t i = 0; i < voices; i++) {
        auto target_pitch = pitch * channel_spread_multipliers[i];
        active_pitches[i] = target_pitch;

        if (stop_previous)
          thea::ym2612::stop_note(i);

        thea::ym2612::set_channel_freq(i, active_pitches[i] * pitch_bend_multiplier);
        thea::ym2612::play_note(i);
      }
    }
  }

  virtual void note_off(uint8_t note) {
    // This situation shouldn't happen, but if it does, don't panic.
    if (note_stack.is_empty())
      return;

    note_stack.pop(note);
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

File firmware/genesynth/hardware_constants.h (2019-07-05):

#ifndef THEA_HARDWARE_CONSTANTS_H
#define THEA_HARDWARE_CONSTANTS_H

#define STATUS_LED 13

/* YM2612 Constants */

// Pin 14-21 to YM DATA
// NOTE: The PCB motherboard reverses the order!
#define YM_DATA 21
// Pin 33 to YM IC
#define YM_IC 33
// Pin 32 to YM A1
#define YM_A1 32
// Pin 31 to YM A0
#define YM_A0 31
// Pin 30 to YM WR
#define YM_WR 29
// Pin 29 to YM CS
#define YM_CS 28
// Pin 28 to YM RD
#define YM_RD 30
// How long to hold the WR and CS lines when writing data.
// The datasheet indicates this should be *at least* 200nS, but it appears
// that a setting of (200) ~2,000uS ensures that the chip always gets our messages.
#define YM_WRITE_WAIT 11 // * 10uS
// The maximum about of uC cycles to wait for the YM2612 to be ready to receive data.
// This is around 10,000uS.
#define YM_MAX_WAIT_CYCLES 10000
// How long to hold the reset line.
// According to bus timing documents, we must hold the line low for at least
// 192 cycles. At 8hmz, that's 24 microseconds.
#define YM_RESET_WAIT 24 // uS
// The YM2612 clock is driven by a PWN pin
#define YM_CLOCK 4
/*
Ideal clock is 7.67, but it seems the teensy can't do that accurately.
Use 7.5, which is accurate & stable (verified by external tuner) & more
than close enough.
*/
#define YM_CLOCK_FREQ 7500000

/* Display & button constants */
// Display is on SPI.
#define DISPLAY_CS 10
#define DISPLAY_DC 9
#define DISPLAY_RESET 8
#ifndef DISPLAY_RATE
#define DISPLAY_RATE 66666 // 1/15th of a second in microseconds.
#endif
#ifndef U8G2_INITIALIZATION
#define U8G2_INITIALIZATION                                                                                            \
  U8G2_SH1106_128X64_NONAME_F_4W_HW_SPI u8g2(/* rotation=*/U8G2_R2, /* cs=*/DISPLAY_CS, /* dc=*/DISPLAY_DC,            \
                                             /* reset=*/DISPLAY_RESET);
#endif
// Buttons use descending pins from the first button's pin.
#define BUTTON_ONE 27

/* Synth core constants */
#define DEBUG_EEPROM_RW 0
#define EEPROM_PATCH_PRESENT_ADDR 0x09
#define EEPROM_PATCH_ADDR 0x10

#ifdef HARDWARE_CONSTANTS_OVERRIDE
#include "hardware_constants_override.h"
#endif

#endif

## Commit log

2018-06-18 Simple note masking and velocity
2018-06-20 Remove velocity -> volume for now
2018-07-24 Fix frequency calculation and refactor a bit
    [midi.h, ym2612.cpp]
2018-10-07 Add schematic and PCB for the audio amplifier board
    [Mega Amp-B.Cu.gbr, Mega Amp-B.Mask.gbr, Mega Amp-B.SilkS.gbr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]
2018-10-07 Add debug for missing controlllers
    [midi_interface.cpp]
2018-10-11 Add missing pulldown resistors
    [Mega Amp.sch]
2018-10-14 Add motherboard
    [Genesynth.kicad_pcb, Genesynth.sch]
2018-10-14 Add note about PCB motherboard inverting direction of data pins
    [ym2612.cpp]
2018-10-14 Updating motherboard
    [Genesynth.kicad_pcb, Genesynth.sch]
2018-10-19 Add display PCB
    [Display.kicad_pcb, Display.sch]
2018-10-25 Add PDF for Genesynth schematic
2018-10-28 Switch to final hardware
2018-10-28 Update hardware pcbs
    [Display.kicad_pcb, Genesynth.kicad_pcb]
2018-10-29 Add buttons support and patch loading via buttons
    Closes #3
2018-10-30 Wait on serial monitor when button 3 is pressed on boot
2018-11-01 Fix bootup debug button
    [genesynth.ino, synth.cpp]
2018-11-20 Pitch bend support
2019-01-14 Fix Hz -> Chip Freq calculation
    [ym2612.cpp]
2019-01-21 Add case design
2019-01-21 Add gerbers
    [Display-B.Cu.gbl, Display-B.Mask.gbs, Display-B.SilkS.gbo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]
2019-04-30 Fix parameter direction and display
    [synth.cpp]
2019-07-01 Fix various issues with compilation
    [genesynth.ino, synth.cpp]
2019-07-05 Add simulator (#22)
    * Get code compiling under clang with stubs for the hardware.
    * Implement the display stuv
    * Add button stub
    * Implement filesystem stub
    * Move simulator to top-level directory
    * Simplify makefile
    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
2019-07-19 Add ability to map velocity
2019-09-18 Add sysex command to send the TFI data for the current patch
2019-09-18 Fix small bug with OP 4 AM writes
    [ym2612.cpp]

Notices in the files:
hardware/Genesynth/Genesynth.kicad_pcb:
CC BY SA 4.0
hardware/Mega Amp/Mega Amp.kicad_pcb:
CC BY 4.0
